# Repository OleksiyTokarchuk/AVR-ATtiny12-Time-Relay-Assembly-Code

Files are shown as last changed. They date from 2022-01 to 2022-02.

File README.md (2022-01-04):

# AVR-ATtiny12-Time-Relay-Assembly-Code
Assembly code based AVR ATtiny12 time relay with 7-segment time indicators
<ul>
 <li>Set RSTDISBL fuse bit</li>
 <li><b>Caution!</b> Don't forget to add mised resistors to limit current through 7-segment indicators!<br><a href="https://github.com/OleksiyTokarchuk/AVR-ATtiny12-Time-Relay-Assembly-Code/blob/main/Board/SchematicDesign.pdf">Check this</a></li>
</ul>
<hr>
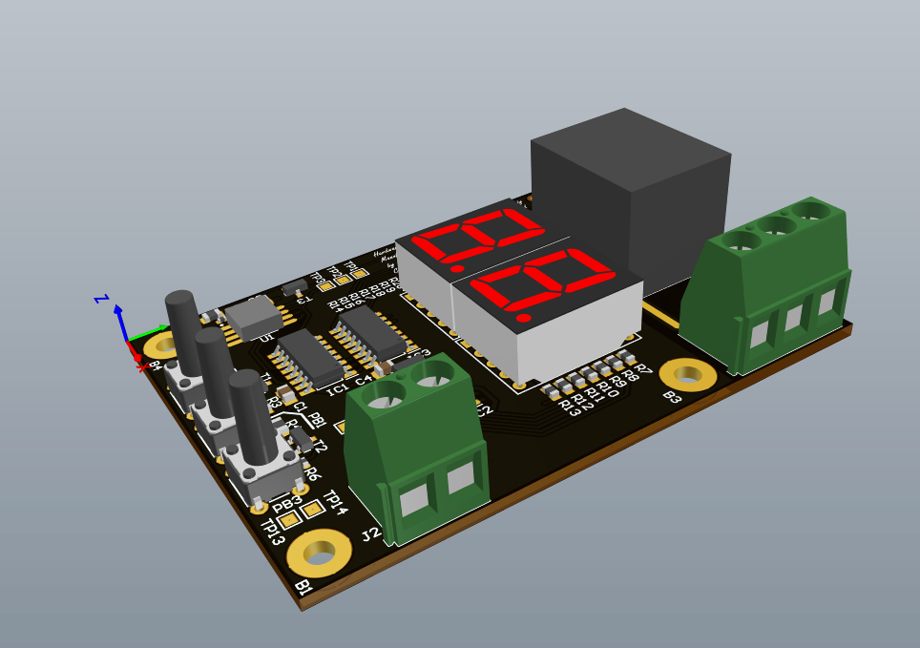
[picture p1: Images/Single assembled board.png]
AVR assembler time relay single board

<hr>
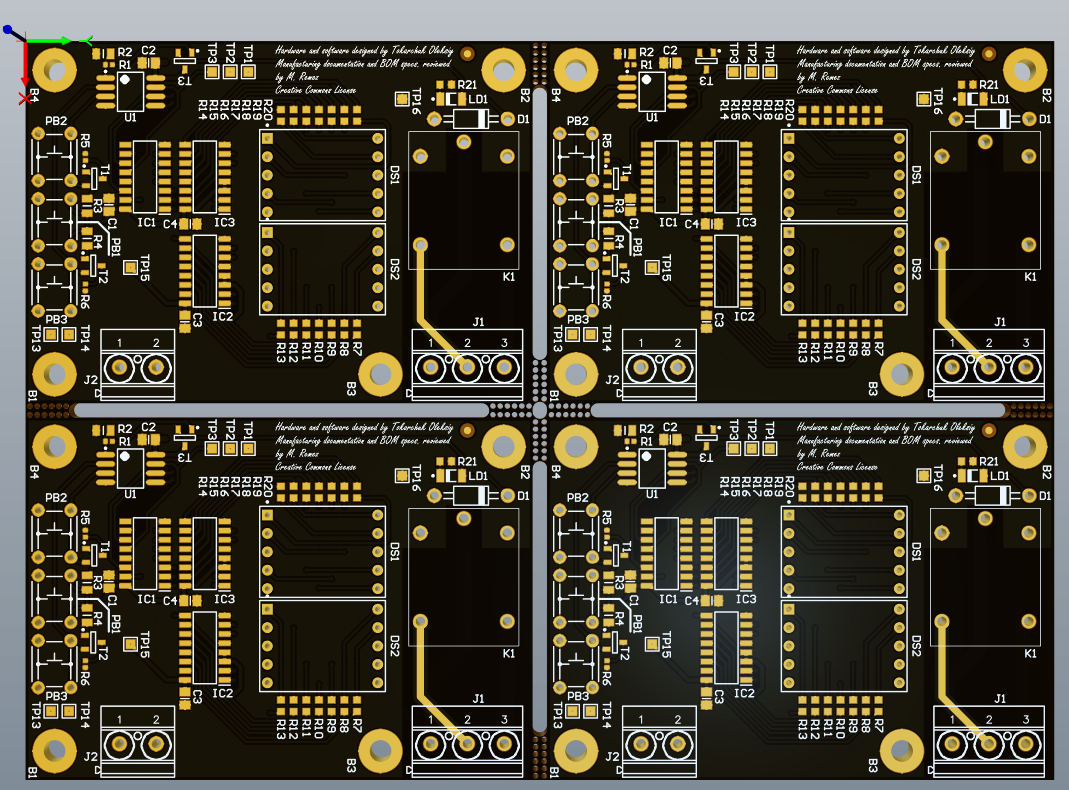
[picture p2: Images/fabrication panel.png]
AVR assembler time relay fabrication panel

<hr>
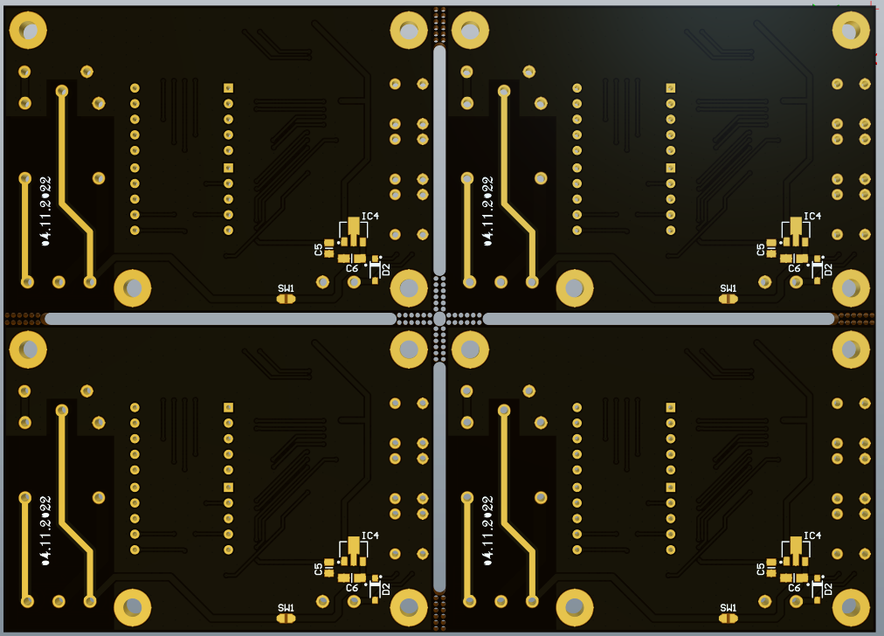
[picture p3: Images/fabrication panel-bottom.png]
AVR assembler time relay fabrication panel bottom view

<hr>
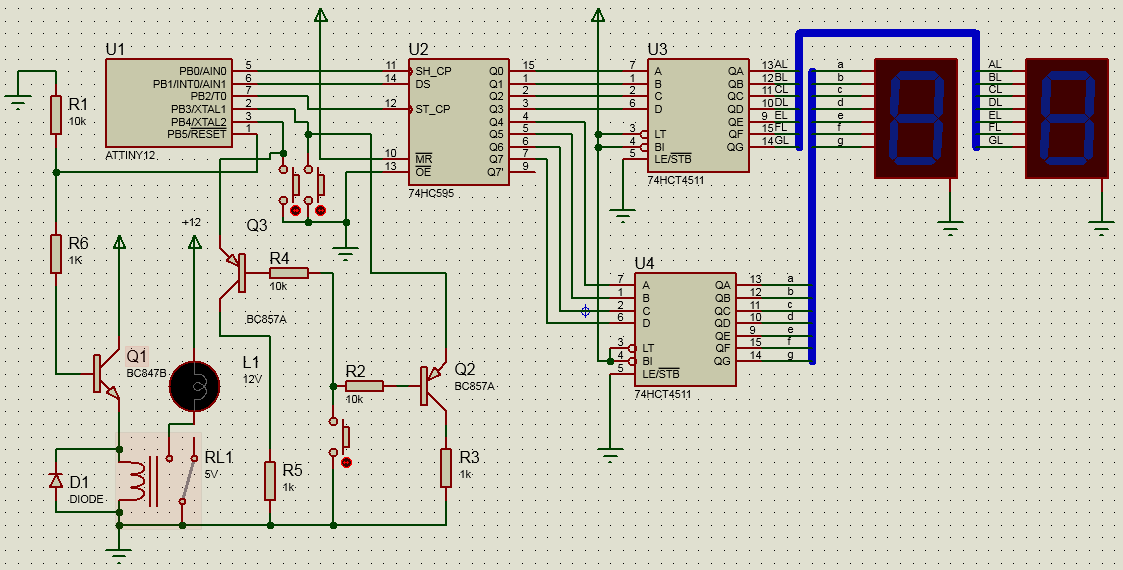
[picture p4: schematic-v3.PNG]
AVR assembler time relay


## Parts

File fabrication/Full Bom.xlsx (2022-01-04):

Comment | Description | Designator | Footprint | LibRef | Quantity
Use only in PCB | Fiducial Target | FTG1 | FIDUCIAL_TOP_C100-200 | FIDUCIAL_TARGET_C100-200 | 1
Test Point | Test Point | TP1, TP2, TP3, TP13, TP14, TP15, TP16 | TPS127 | SMD_PAD_1.27X1.27MM | 7
Switch | 2 SMD Pads for Bound by Solder Drop | SW1 | JUMPSMD0805_G50 | JUMPSMD0805_G50 | 1
Red | LED Red 1C 2A | LD1 | LED_AVAGO_HSMC-C150 | LED_AVAGO_HSMC-C150 | 1
Push Button | Push-Button Switch SPDT | PB1, PB2, PB3 | PB_ALPS_SKHHDTA010 | PB_ALPS_SKHHDTA010 | 3
Plated Hole | Single Terminal Socket | B1, B2, B3, B4 | MTG300_600 | PLATED_HOLE3.0_PAD6.0 | 4
MBR0530PbF | Schottky Diode | D2 | SOD3715X145N | MBR0530PbF | 1
L78L05ACUTR | 3-Terminal Regulator 1=OUT 2=GND 3=IN | IC4 | SOT89 | L78L05ACUTR | 1
HF3FF_005-1ZST | Relay or Contactor | K1 | HF3FF0051ZST | HF3FF_005-1ZST | 1
HDSP-H153 | LED 7-SEG 14.2MM CC RED RHD RHD | DS1, DS2 | FP-HDSP-H153-MFG | CMP-18395-000002-1 | 2
BC857B | PNP Transistor | T1, T2 | SOT95P230X110-3N | BC857B | 2
BC847B | NPN Transistor | T3 | SOT95P230X110-3N | BC847B | 1
ATtiny12-8SU | 8-bit AVR Microcontroller, 4.0-5.5V, 1KB Flash, 64 Bytes EEPROM, 8-pin SOIC, Industrial Grade (-40°C to 85°C), Pb-Free | U1 | 8S2_M | CMP-0093-00168-2 | 1
270 | Resistor - 1% | R7, R8, R9, R10, R11, R12, R13, R14, R15, R16, R17, R18, R19, R20, R21 | RESC1608X55N | R0603_270R_1%_0.1W_100PPM_75V | 15
100nF | Non-polarised capacitor | C1, C2, C3, C4 | CAPC2012X88N | CC0805_100NF_50V_10%_X7R_YUDEN_UMK212B7104KGH | 4
74HCT4511D,652 | Integrated Circuit | IC2, IC3 | SOIC127P600X175-16N | 74HCT4511D,652 | 2
74HC595D | Integrated Circuit | IC1 | SOIC127P600X175-16N | 74HC595D | 1
10uF | Polarised capacitor | C6 | CAPMP3216X180N | CTE3216-18_10UF_10V_10%_LESR1800 | 1
10k | Resistor - 1% | R2, R3, R4 | RESC2012X60N | R0805_10K_1%_0.125W_100PPM | 3
1uF | Non-polarised capacitor | C5 | CAPC2012X135N | CC0805_1UF_50V_10%_X7R_YUDEN_UMK212B7105KGH | 1
1N4007 | Diode | D1 | DO-41 | 1N4007 | 1
1k | Resistor - 1% | R1, R5, R6 | RESC1005X40N | R0402_1K_1%_0.0625W_100PPM | 3
 | Terminal Block, 2 Positions, Screw Connection | J2 | PHOENIX_1715721 | PHOENIX_1715721 | 1
 | Terminal Block, 3 Positions, Screw Connection | J1 | PHOENIX_1715734 | PHOENIX_1715734 | 1

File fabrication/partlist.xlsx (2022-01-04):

Comment | Designator | Footprint | Quantity | JLCPCB PART
100nF | C1, C2, C3, C4 | CAPC2012X88N | 4 | C136621
270 | R7, R8, R9, R10, R11, R12, R13, R14, R15, R16, R17, R18, R19, R20, R21 | RESC1608X55N | 15 | C22966
10k | R2, R3, R4 | RESC2012X60N | 3 | C17414
1k | R1, R5, R6 | RESC1005X40N | 3 | C11702
BC857B | T1, T2 | SOT95P230X110-3N | 2 | C59205
BC847B | T3 | SOT95P230X110-3N | 1 | C8664

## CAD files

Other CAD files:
bin/tinytimer.obj

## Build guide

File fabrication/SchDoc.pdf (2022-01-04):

# Time relay

# GND TP1 TP2 TP3

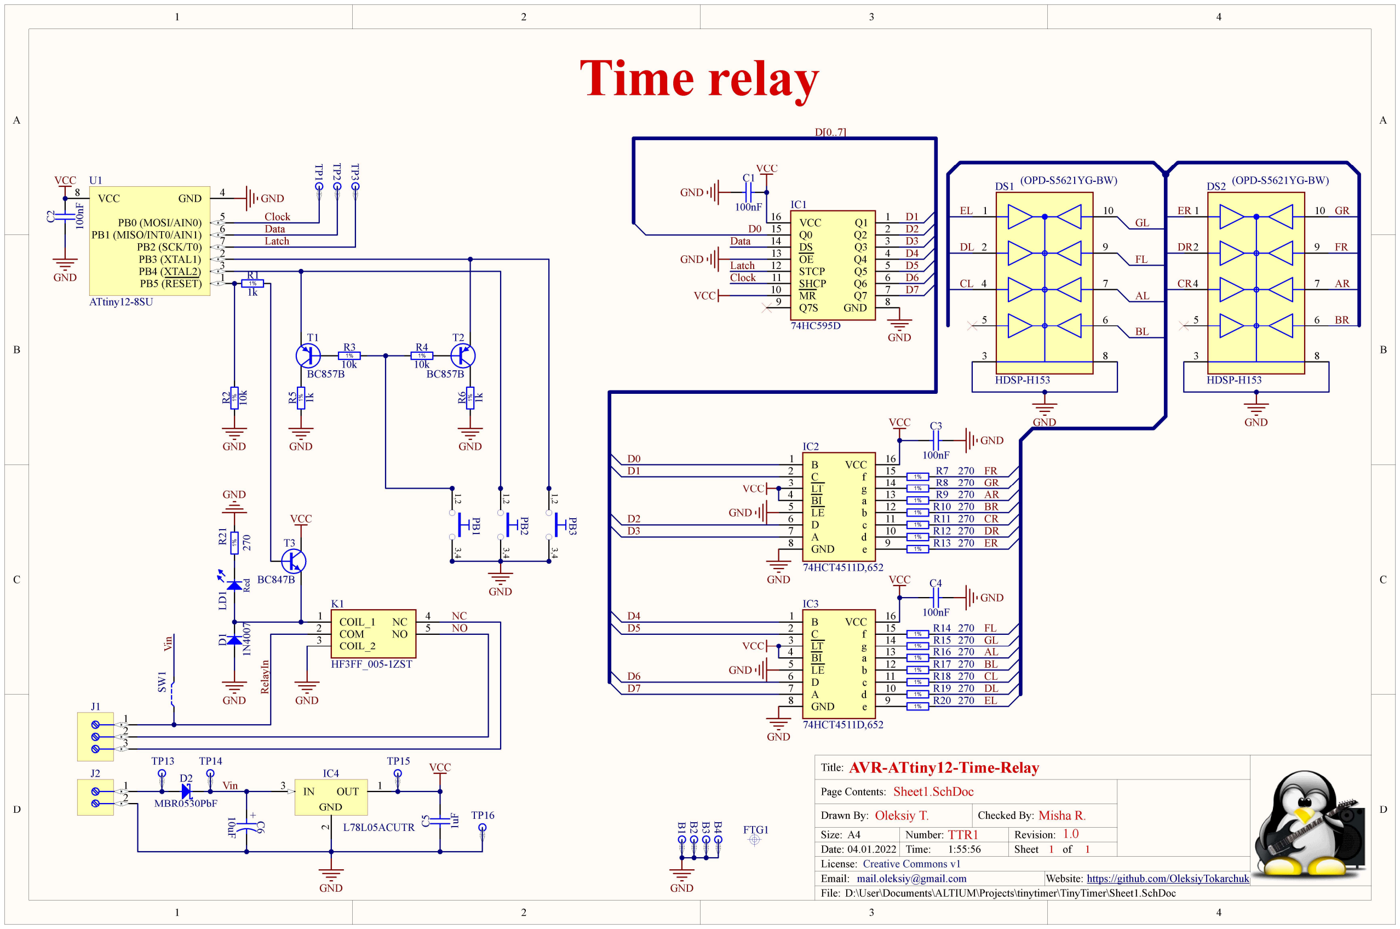
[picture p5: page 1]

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
## AVR-ATtiny12-Time-Relay

TTR1 | 1.0
04.01.2022 1:55:56

D:\User\Documents\ALTIUM\Projects\tinytimer\TinyTimer\Sheet1.SchDoc

Title:

Size: | Number:
Date:

File:

Revision:
Time: | Sheet | of

A4

Drawn By: Oleksiy T. | Misha R. Checked By:

License: Creative Commons v1
Email: mail.oleksiy@gmail.com

Page Contents: Sheet1.SchDoc

Website: https://github.com/OleksiyTokarchuk

PB5 (RESET) | 1
PB3 (XTAL1) | 2
PB4 (XTAL2) | 3
GND | 4
PB0 (MOSI/AIN0) | 5
PB1 (MISO/INT0/AIN1) | 6
PB2 (SCK/T0) | 7

VCC 8

U1

ATtiny12-8SU

GND

VCC C² | 100nF

GND

T3

BC847B

T2

BC857B R²¹% 10k

GND

1%

R1
1k

VCC

COIL_1 1
COM 2
COIL_2 3
NC | 4
NO | 5

K1

HF3FF_005-1ZST

GND D¹ 1N⁴⁰⁰⁷

GND RelayIn

NC

NO¹,2 3,4 | PB1 | 1,2 3,4 | PB2 | 1,2 3,4 | PB3

GND

T1

BC857B

1%

R3
10k

1%

R4

10k R⁵¹%1k | R⁶¹%1k
GND | GND
Q1 | 1
Q2 | 2
Q3 | 3
Q4 | 4
Q5 | 5
Q6 | 6
Q7 | 7
GND | 8

VCC 16
Q0 15
DS 14
OE 13
STCP 12
SHCP 11
MR 10
Q7S 9

IC1

74HC595D

VCC
C1

100nF

GND

Clock

Data

Latch

Clock
Data
Latch

D[0..7]

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
LT 3
BI 4
LE 5
D

6
A

7
GND 8
VCC | 16
f | 15
g | 14
a | 13
b | 12
c | 11
d | 10
e | 9

IC2

74HCT4511D,652

VCC

VCC | C3
| 100nF

GND

B

1
C

2
LT 3
BI 4
LE 5
D

6
A

7
GND 8
VCC | 16
f | 15
g | 14
a | 13
b | 12
c | 11
d | 10
e | 9

IC3

74HCT4511D,652

VCC | C4
| 100nF

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
1% R7 270

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
HDSP-H153

1% | R8 270
1% | R9 270
1% | R10 270
1% | R11 270
1% | R12 270
1% | R13 270
1% | R14 270
1% | R15 270
1% | R16 270
1% | R17 270
1% | R18 270
1% | R19 270
1% | R20 270

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
HDSP-H153

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
GND | GND

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
(OPD-S5621YG-BW) | (OPD-S5621YG-BW)
IN 3 | 2
OUT | 1

GND

IC4

L78L05ACUTR

GND

+C6 10uF | C⁵ | 1uF

D2

MBR0530PbF

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
Vin SW¹ Vin

FTG1 B1 B2B3 B4

GND

TP13 | TP14 | TP15

TP16 Red LD¹ R²¹ 1% 270

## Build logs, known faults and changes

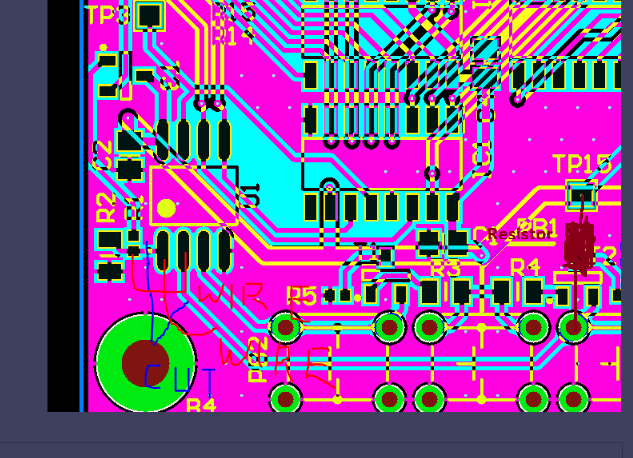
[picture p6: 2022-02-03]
firmware&hardware fixes/PCB cut and wire before rev 2.0.PNG

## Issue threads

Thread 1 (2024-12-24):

help me, I cannot upload the hex file to the ATtiny12, meaning I cannot burn the program

Chenjiek, 2024-12-24:
Hello, my friend, I have tried many methods, but I cannot upload the hex file to the ATtiny12, meaning I cannot burn the program. Can you help me? Which software and hardware should I use?

OleksiyTokarchuk, 2025-05-09:
You may use any software you want. Make sure that you don't have SPI programming disabled by corresponding fuse bit. Sometimes happens if you order ATTINY MCU from AliExpress. The solution is to reset this fuse bit in high voltage programming mode (read datasheet)
Use AVR dude for example https://github.com/avrdudes/avrdude
With any AVR ISP usb interface you can buy online

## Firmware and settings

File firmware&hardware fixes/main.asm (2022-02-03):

;Author: Oleksiy Tokarchuk 
;mail.oleksiy@gmail.com

.def data        = r16 			            ;Software shift register
.def i           = r17				    ;Register that stores cycle iterator
.def p           = r18				    ;Pointer to data in table for 7-segment indicators 
.def dataout     = r19		                    ;Register that outputs data from shift into IO space 
.def tableaddr   = r20	          	            ;Register that stores first byte point in table 
.def temp        = r21
.def time        = r22
.def setpoint    = r23
.def buttonstate = r24

.equ clock = 0					      ;clock pin
.equ cs    = 2					      ;chip selsct pin
.equ mosi  = 1					      ;sdout pin
.equ mask  = 0b00000010 			      ;mask where 1 corresponds mosi pin position in PORTx register

.equ plus  = 5
.equ minus = 4
.equ relay = 3

.eseg
	.db 0x01 ;EEPROM location for last used setpoint to store it
                 ;will be implemented in future
.cseg

.org 0x00 rjmp RESET

; the best place to access table by single relative address LOW register 
table:    		    .db 0x00, 0x01, 0x02, 0x03, 0x04, 0x05, 0x06, 0x07, 0x08, 0x09, \
			        0x10, 0x11, 0x12, 0x13, 0x14, 0x15, 0x16, 0x17, 0x18, 0x19, \
			        0x20, 0x21, 0x22, 0x23, 0x24, 0x25, 0x26, 0x27, 0x28, 0x29, \
			        0x30, 0x31, 0x32, 0x33, 0x34, 0x35, 0x36, 0x37, 0x38, 0x39, \
			        0x40, 0x41, 0x42, 0x43, 0x44, 0x45, 0x46, 0x47, 0x48, 0x49, \
			        0x50, 0x51, 0x52, 0x53, 0x54, 0x55, 0x56, 0x57, 0x58, 0x59, \
			        0x60, 0x61, 0x62, 0x63, 0x64, 0x65, 0x66, 0x67, 0x68, 0x69, \
			        0x70, 0x71, 0x72, 0x73, 0x74, 0x75, 0x76, 0x77, 0x78, 0x79, \
			        0x80, 0x81, 0x82, 0x83, 0x84, 0x85, 0x86, 0x87, 0x88, 0x89, \
			        0x90, 0x91, 0x92, 0x93, 0x94, 0x95, 0x96, 0x97, 0x98, 0x99

RESET:
	ldi tableaddr, 0x02
	clr ZH
	sbi DDRB, mosi			                ;data
	sbi DDRB, clock			                ;clock
	sbi DDRB, cs			                ;latch
	cbi DDRB, plus
	sbi DDRB, relay
	ldi temp, (1 << plus)|(1 << minus)
	out PORTB, temp                                 ;pull-up for buttons
	rcall EEPROMRead
	in setpoint, EEDR
	mov p, setpoint
	rcall print
	clr temp
	ldi time, 0
loop:
	in buttonstate, PINB
	andi buttonstate, 0b00110000
	cpi buttonstate, (0 << plus)|(1 << minus)
	breq increment
	cpi buttonstate, (1 << plus)|(0 << minus)
	breq decrement
	cpi buttonstate, 0x00
	breq start
	rjmp loop

start:
	cpi setpoint, 0
	breq error              ;setpoint can't be zero
	rcall EEPROMRead
	in temp, EEDR
	cp temp, setpoint
	brne notequal
NewSetpointSaved:
	mov time, setpoint
	sbi PORTB, relay
softtimer:
	rcall delay1s
	dec time
	mov p, time
	rcall print
	cpi time, 0
	brne softtimer
	cbi PORTB, relay
	mov p, setpoint
	rcall print
	rjmp loop
error:
	rjmp loop
notequal:
	out EEDR, setpoint
	rcall EEPROMWrite
	rjmp NewSetpointSaved

increment:
	rcall delay
	sbrc buttonstate, plus
	rjmp loop
	inc setpoint
	cpi setpoint, 99
	brsh setpoint_maximum
maximum:
	mov p, setpoint
	rcall print
	rcall delay
	rjmp loop
setpoint_maximum:
	ldi setpoint, 99
	rjmp maximum

decrement: 
	rcall delay
	sbrc buttonstate, minus
	rjmp loop
	dec setpoint
	cpi setpoint, 1
	brlo setpoint_minimum
minimum:
	mov p, setpoint
	rcall print
	rcall delay
	rjmp loop
setpoint_minimum:
	ldi setpoint, 1
	rjmp minimum

send: 					;Software defined shift register
	in temp, PORTB
	andi temp, 0b00011000
	clr i
	cbi PORTB, cs
byte:
	cbi PORTB, clock
	bst data, 7
	bld dataout, mosi
	andi dataout, mask
	or dataout, temp
	out PORTB, dataout
	sbi PORTB, clock
	lsl data
	inc i
	cpi i, 8
	brne byte
	sbi PORTB, cs
	ret

print:					;subroutine that prints data on 7-segmet indicators 
	add tableaddr, p
	mov ZL, tableaddr
	lpm
	mov data, R0
	bst data, 0
	bld temp, 3
	bst data, 1
	bld temp, 0
	bst data, 2
	bld temp, 1
	bst data, 3
	bld temp, 2
	bst data, 4
	bld temp, 7
	bst data, 5
	bld temp, 4
	bst data, 6
	bld temp, 5
	bst data, 7
	bld temp, 6
	clr data
	mov data, temp
	rcall send
    sub tableaddr, p
	ret

delay:
  	ldi  r27, 195
    	ldi  r28, 205
Level1: 
	dec  r28
    	brne Level1
    	dec  r27
    	brne Level1
    	rjmp PC+1
	ret

delay1s:
  	ldi r27, 6
  	ldi r28, 19
  	ldi r29, 174
Level2: 
	dec r29
  	brne Level2
  	dec r28
  	brne Level2
  	dec r27
  	brne Level2
  	rjmp PC+1
	ret
	
EEPROMRead:
    ldi temp, 0x00
	out EEAR, temp
	sbi EECR, EERE
WaitRead:
	sbic EECR, EERE
	rjmp WaitRead
	ret

EEPROMWrite:
	ldi temp, 0x00
	out EEAR, temp
	sbi EECR, EEMWE
	sbi EECR, EEWE
WaitWrite:
	sbic EECR, EEWE
	rjmp WaitWrite
	ret

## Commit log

2021-12-31 add beta version of schematic
    make sure that resistor values should be recalculated
2022-01-01 incorrect START button connection
2022-01-01 Corrected schematic
2022-01-01 New version of schematic
2022-01-01 Corrected buttons scan delay
    [main.asm]
2022-01-01 add EEPROM support
    EEPROM stores last setpoint value when start button is pressed
2022-01-01 Add firmware release
    [tinytimer.obj]
2022-01-01 schematic v3
2022-01-01 add ability to see zero when timer done countdown
2022-01-03 Add first revision of board schematic
2022-01-04 fabrication files for PCB
    [Full Bom.xlsx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]
2022-01-04 Add schematic and other drawings
2022-02-03 Critical firmware and hardware fixes before rev 2
    In order to fix hardware mistakes when routing data bus bits for indicators I wrote some firmware fixes.
    Open drain output for reset pin worked incorrectly that why I replaced relay and button pin. Button pin must have external pull-up
    [main.asm]
